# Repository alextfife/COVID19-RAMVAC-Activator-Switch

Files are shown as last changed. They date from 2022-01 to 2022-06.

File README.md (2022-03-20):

# COVID-AirLock

# NOTICE: There has been an issue with the tracing on these, will update once testing has been done. Transfering from kiCAD to EasyEDA removed some traces. 

Dental Office Air Filter Printed Circuit Board (PCB) Activation Switch. Inspired by the events of COVID-19.
This is a modification of a system Designed by RAMVAC Dental Vacuum System. 

<h2>Where did this come from?</h2>
A small minority of dental offices peppered around the United States in the early 2000's installed similar systems within their buildings that allow for air filtration per room, and in most cases, per 'area'. That is, it would be an inlet with 3 walls but no door, thus no closed in air source. Due to bad breath, debris from dental procedures, and sick patients, these filters were installed. 
Although its been roughly 20 years, this practice is not standard, or very popular. However that popularity is rising.


This filtration system is based almost completely on the saw dust collection filters that are installed at sawmills. However at a sawmill the power cost is astronomical due to all the vacuums being on for older systems. Newer systems use switches to activate which vacuum tubes receive suction, and to power on the vacuum.

<br>
Interestingly enough, RAMVAC produces their own switches for their current system. Theres however uses 4x the Wattage mine does. Unfortunately, my switches do not have LED's installed in the switch. 
Check theres out here: https://www.dentalez.com/product/remote-switch-panel/ 

During the COVID-19 pandemic of 2020-present, many dental offices are trying to implement this system now. 

<h2>So what is this project?</h2>
This github page is the evolution of the activator switch. The switch uses a sinusoidal signal to activate both the room's individual vacuum, and to open the aperature for that 'room's tube. 

This project is the creation of a wired switch that is more power efficient and cost efficient to produce than buy from the manufacture. 

<h2>Design Evolution</h2>
The switches are not my original design. The original design is without a patent. 
<h3>Some issues with the old, 'prototype' design. </h3>
<ol><li>It took AA batteries</li>
<li>The batteries corroded a lot and most units were switched out or bricks</li>
<li>The board itself had no seal or protection for components, and the copper on many of them was oxidizing.</li>
<li>There is no way to know when the switch had power or was dead until you took apart the switch socket.</li>
<li>The board itself is wider (by a small margin) than the footprint of the switch itself.</li>
</ol>

<h3>Design Evolution</h3>
The original design. None of this was of my doing.




With this, first thing I wanted to do was get rid of the batteries and do basic circuit analysis. 

<!--After downloading open source models of the parts I needed, I had created this. <br>
<img width="402" alt="image" src="https://user-images.githubusercontent.com/26822309/137974134-3fbc9a2d-eff3-42a8-9520-d32c58ee5504.png"><br>-->

<br>
After checking PCB standards and compliance with the manufacturers, this was my first batch. I planned to save some money and solder them myself. <br>

<br>
Solding such small parts, and not having the funds for a microsolder meant I needed to tweak my design and send it to get fabricated and have the parts soldered on at the manufacturer. <br>
<!--<img width="486" alt="just the chip HQ" src="https://user-images.githubusercontent.com/26822309/137974613-43e77384-697c-4356-9c4e-b56fbe8ef63c.png">--><br>
To interface with the room like the old boards did, then I modified USB cables and was able to get them 5Vin as to not burn my boards.<br>
assembly<br>

<h2>How to use it?</h2>
<h3>Connections</h3>
The boards are plugged in to the wall via USB adapter to any outlet. Therefore, you can hot switch the system around. <br>
<!--![IMG_3695 Medium](https://user-images.githubusercontent.com/26822309/137982630-042878fc-2eb9-48a7-97a8-76712cf9e39f.png)-->

assembly<br>
"Output" as seen on the board sends the signal from the board to a 2 pin terminal hardwired into the room. The "Switch" I/O on the board is where the USB power comes from. 
<h3>Usage</h3>
doctor<br>
<i>Pictured: Dr. Robinette using vacuum tube after being activated.</i><br>
To use the airlocking vacuum system, one must simply turn it on and wait for about 10 seconds for the vacuum to charge to full sucking capacity. Then simply direct the tube to the patients breathing aperatures as shown below.<br>
patient

<h2>Where is this?</h2>
My work as seen here is implemented at Gulf Coast Dental, in Bluewater Bay, FL. Please visit the website that I also designed! https://gulfcoastdental.com 

<br>
<i>I had express permission to photograph healthcare professionals and patients pictured to be in this documentation</i><br>

<h2>Do you want this?</h2> 
Please contact me, and I will promplty get in touch with you! 

I offered my design to the parent companyand I also applied for a position as product development engineer. I was rejected for the position. 

Under fair use, I have attached all designs and files to this repo for the unicorns out there whom this project might benefit!

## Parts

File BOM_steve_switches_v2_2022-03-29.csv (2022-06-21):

ID | Name | Designator | Footprint | Quantity | Manufacturer Part | Manufacturer | Supplier | Supplier Part | Price | Pins | 3DModel | JLCPCB SMD | LCSC Assembly | Paste Type | Capacitance | Contributor | Resistance (Ohms) | SMT Type | link
1 | C0603 | C1-1N | C0603 | 1 | CL10B102JB8NNNC | SAMSUNG | LCSC | C51203 | 0.007 | 2 | C0603_L1.6-W0.8-H0.8 |  |  |  | 1nF | 立创EDA官方封装库 |  |  | https://item.szlcsc.com/362304.html
2 | C0603 | C2-120N | C0603 | 1 | CL10F104ZB8NNNC | SAMSUNG | LCSC | C1688 | 0.006 | 2 | C0603_L1.6-W0.8-H0.8 | Yes | Yes | expand | 120nF | 立创EDA官方封装库 |  | Extend | https://item.szlcsc.com/362304.html
3 | R0603 | R1-1M | R0603 | 1 | TC0325B1004T5E | Uniroyal Elec | LCSC | C185077 | 0.045 | 2 | R0603_L1.6-W0.8-H0.8 |  |  |  |  | layout | 1M |  | https://item.szlcsc.com/137208.html
4 | R0603 | R2-10K | R0603 | 1 | TC0310B1002T5E | Uniroyal Elec | LCSC | C190321 | 0.135 | 2 | R0603_L1.6-W0.8-H0.8 |  |  |  |  | layout | 10K |  | https://item.szlcsc.com/137208.html
5 | SOIC-14_L8.7-W3.9-P1.27-LS6.0-BL | MC | SOIC-14_L8.7-W3.9-P1.27-LS6.0-BL | 1 | TLC374IDR | TI | LCSC | C130030 | 1.451 | 14 | SOIC-14_L8.6-W3.9-H1.8-LS6.0-P1.27 |  |  |  |  | winter2015 |  |  | https://item.szlcsc.com/7253.html

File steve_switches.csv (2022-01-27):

Id | Designator | Package | Quantity | Designation | Supplier and ref
1 | U1 | SOIC127P600X175-14N | 1 | MC14106BDG
2 | R2 | R_0603_1608Metric_Pad1.05x0.95mm_HandSolder | 1 | 10k
3 | R1 | R_0603_1608Metric_Pad1.05x0.95mm_HandSolder | 1 | 1M
4 | C2 | C_0603_1608Metric_Pad1.05x0.95mm_HandSolder | 1 | 120nF
5 | C1 | C_0603_1608Metric_Pad1.05x0.95mm_HandSolder | 1 | 1nF

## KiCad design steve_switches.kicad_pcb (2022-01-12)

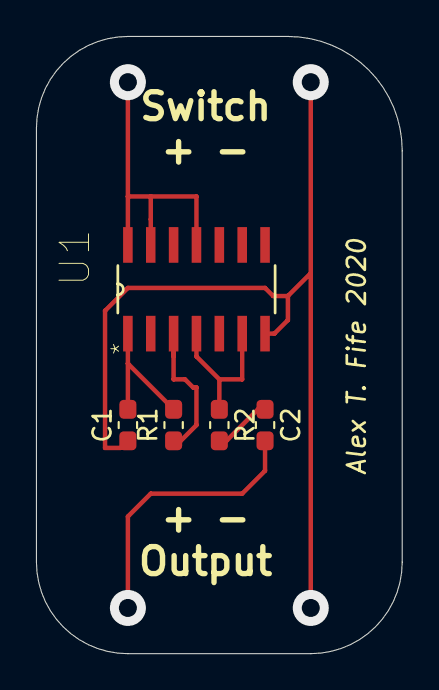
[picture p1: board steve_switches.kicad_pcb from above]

Board: 2 copper layers, 20.3 x 34.3 mm, 5 parts (0 on the bottom side), 6 nets.

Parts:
C1: 1nF; C_0603_1608Metric_Pad1.05x0.95mm_HandSolder
C2: 120nF; C_0603_1608Metric_Pad1.05x0.95mm_HandSolder
R1: 1M; R_0603_1608Metric_Pad1.05x0.95mm_HandSolder
R2: 10k; R_0603_1608Metric_Pad1.05x0.95mm_HandSolder
U1: MC14106BDG; SOIC127P600X175-14N

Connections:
+3.3VA: U1.11, U1.13, U1.14
GND: C1.1, U1.7
unnamed: C1.2, R1.2, U1.1
unnamed: C2.1, R2.2
unnamed: R1.1, U1.3
unnamed: R2.1, U1.4, U1.6

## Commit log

2022-01-12 kiCAD open source MC14106BDG
    This wasn't created by me. I am only sharing it as part of this project
    Supports kiCAD 5.0+
2022-01-12 Add files via upload
    GBR files in a zip. Most PCB manufacturers want it this way
2022-01-12 Add files via upload
    You will need a BOM. I found it easier to go on excel and create my own based on what the manufacturer looks for. However, some may want to use this. I am supplying it here
2022-01-27 Add files via upload
    BOM
    [steve_switches.csv]
2022-06-21 The most up to date Bill of materials
    [BOM_steve_switches_v2_2022-03-29.csv]
